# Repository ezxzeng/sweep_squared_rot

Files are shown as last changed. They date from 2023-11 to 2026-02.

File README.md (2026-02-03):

# Sweep Squared
## An autogenerated split 36 key keyboard
example zmk config at https://github.com/ezxzeng/sweepsq-zmk

## Disclaimer

Please do not rely on the autogenerated files and double check them manually
before sending them off to a PCB fab. The author and other random strangers on the internet have been able to produce
working keyboard prototypes from this repo; this does not mean that everything will work every time.

The author(s) waive(s) responsibility for any damage or regulatory violations caused by using this software (see
license). Please consult your local regulations around radio frequencies and what's allowed for DIY projects in your
country.

left | right | outline
-|-|-
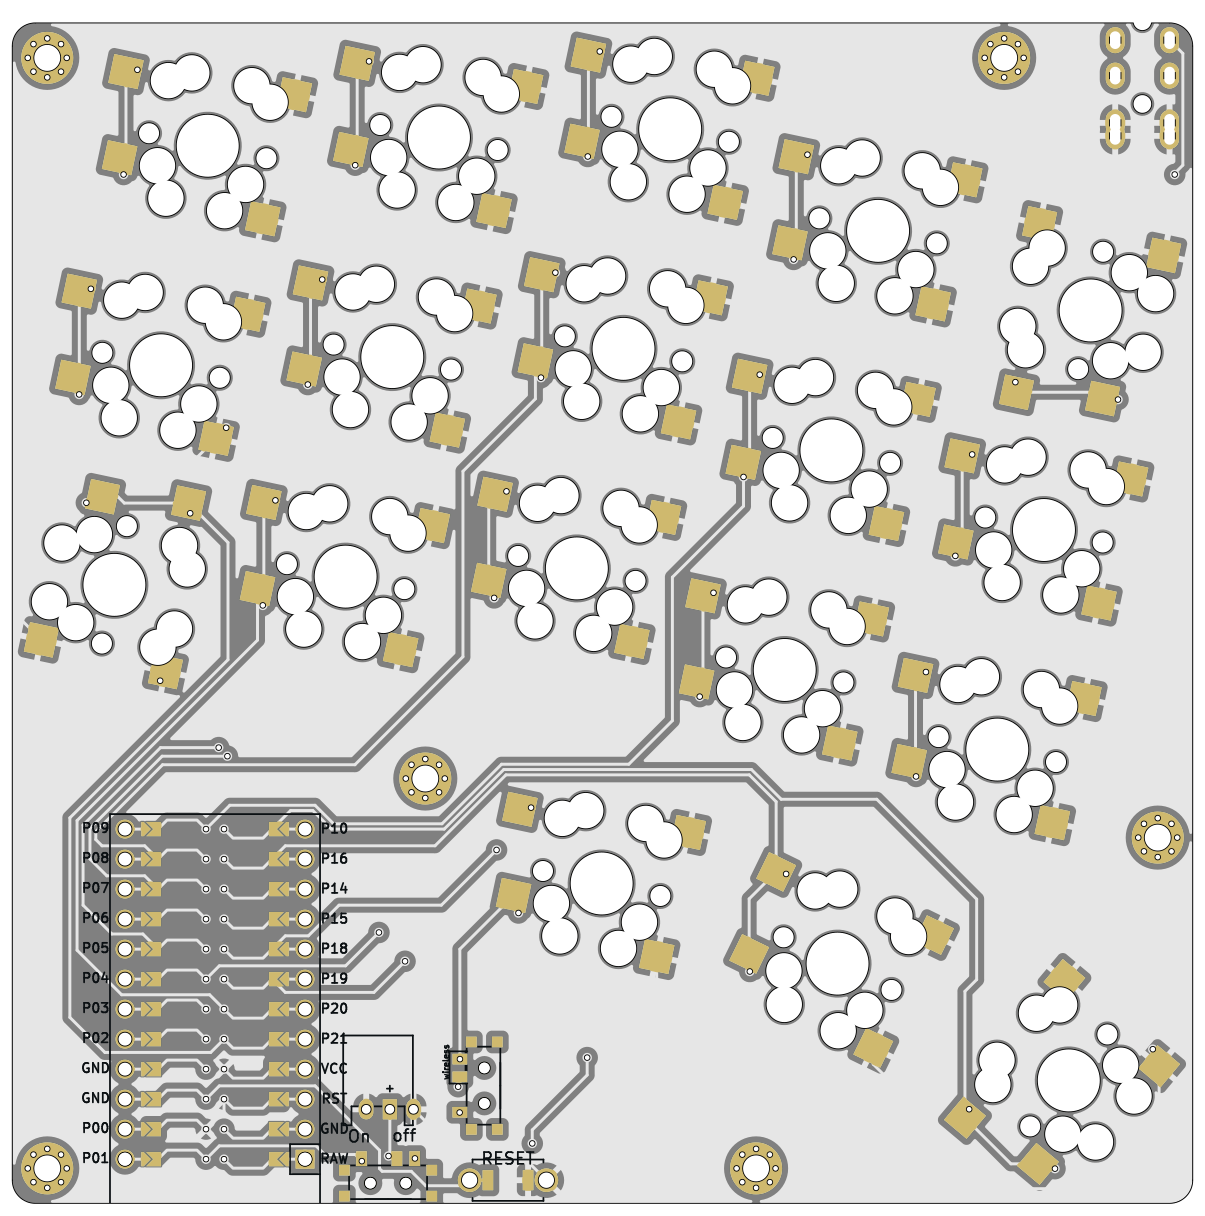
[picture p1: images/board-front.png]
left
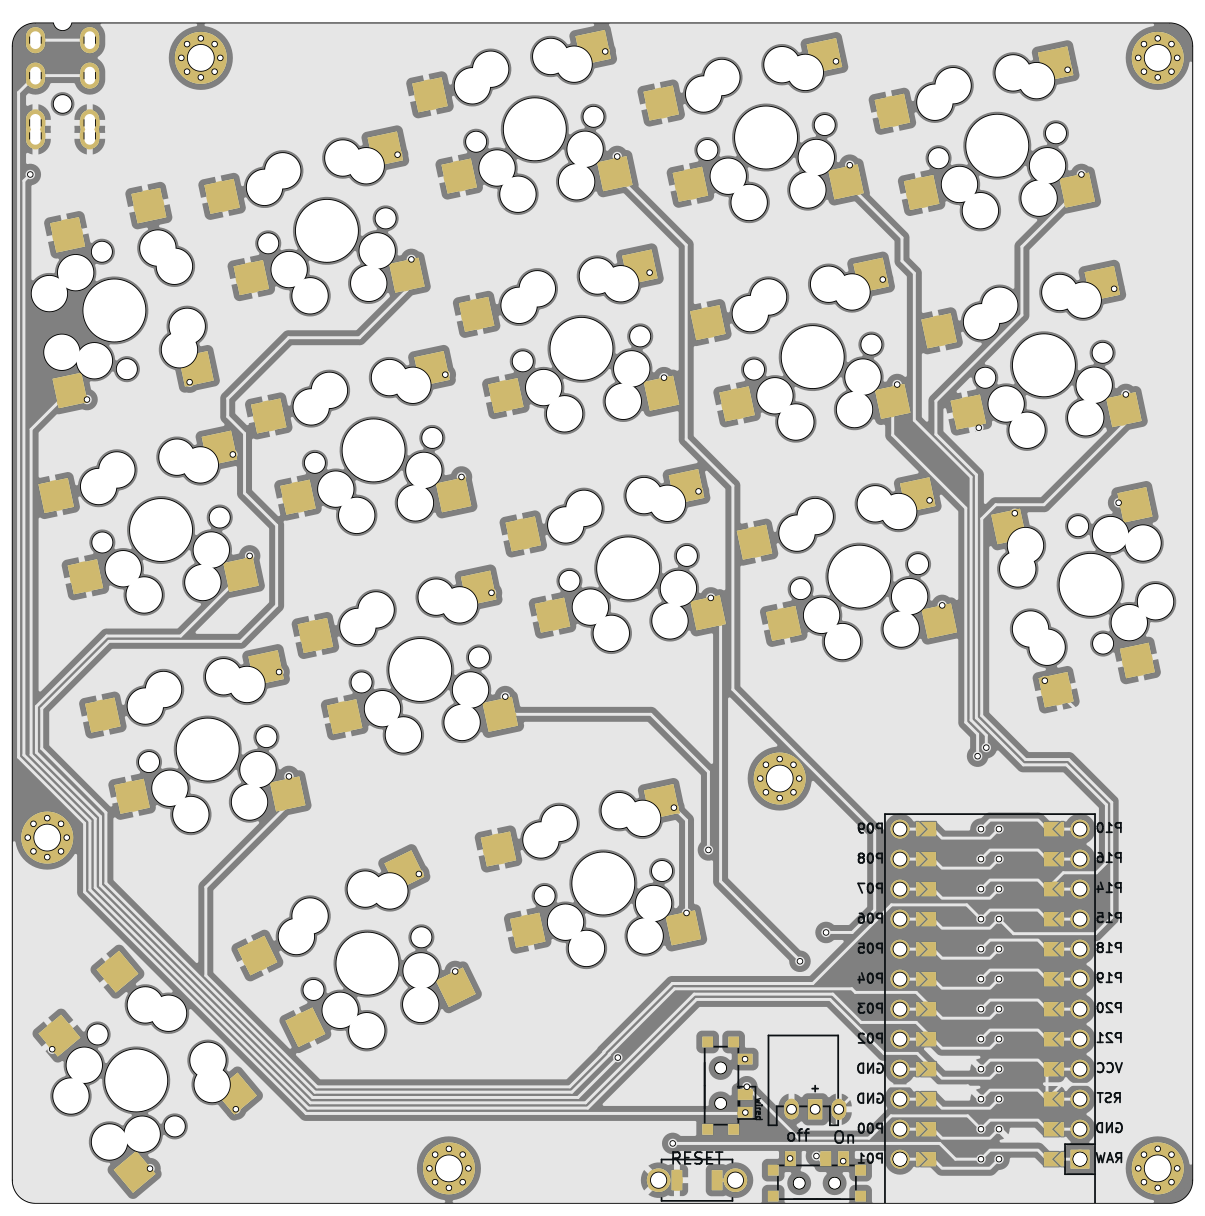
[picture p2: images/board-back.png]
right
 |  | outline

A 5x3 split keyboard with 3 thumb keys. 

## Inspiration

- [bgkeeb](https://github.com/sadekbaroudi/bgkeeb)
	- keyboard pcbs under 100mm x 100mm are cheap
- [cheapis](https://github.com/dotleon/cheapis)
	- sweeps can be rotated for more room and length between the thumb cluster and rest of the keys and still fit within 100mm x 100mm
- [samoklava](https://github.com/soundmonster/samoklava) and [ergogen](https://ergogen.cache.works/) to get keyboard layouts programatically
- [sweep](https://github.com/davidphilipbarr/Sweep) and [swweeep](https://github.com/sadekbaroudi/sweep36) for form factor and diode-less design
- [Lily58](https://github.com/kata0510/Lily58/tree/master)
	- key sockets can be hot swappable, reversible, and compatible with both mx and low profile switches
- [totem](https://github.com/GEIGEIGEIST/totem)
	- sandwich case looks really slick and clean, and can also hide the controller parts that will be located under the palm

## Features

- 100mm x 100mm pcb for really cheap fabrication
- reversible footprint
- programatically generated with [ergogen](https://ergogen.cache.works/) (mostly)
- `footprints/key_switches.js` enables deciding between combinations of MX, Choc, or gateron low profile sockets
- jst battery connector and 7-pin slider switch for battery management
- Same key routing as the [swweeep](https://github.com/sadekbaroudi/sweep36)
- Can be both wired and wireless while maintaining a diodless design
  - Features a toggle button to change whether p0 directs to TRRS or the inner thumb key
  - This does mean that the wired version would only support two thumb keys

## Other considerations
- this design does not support LEDs or displays
- [samoklava's](https://github.com/soundmonster/samoklava) auto routing does not really work here

## Rendering and generation

### Generate config:
```bash
python generate_config.py
```
Alternatively, edit the units of base_units.yaml with files from the `unit_diffs` folder.

For example, to generate a case compatible with gateron low profile keyboards and a 1u thumb key instead of 1.5u:
```bash
python generate_config.py unit_diffs/1u_thumb.yaml unit_diffs/gateron_lp_case.yaml 
```

### Ergogen:
```bash
ergogen .
```

### Case:
```bash
for i in output/cases/*.jscad; do npx @jscad/cli@1 "$i" -of stla; done
```

Alternatively, checkout the [onshape file](https://cad.onshape.com/documents/20657883be99e0a9d477d709/w/83f1c619a76dd7448d8e6516/e/9a5a09390163f484d61154c1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) for nicer cases

### Get board image renderings:
```bash
docker run -v $(pwd):/kikit --entrypoint pcbdraw yaqwsx/kikit:v1.3.0-v7  plot --style style.json routed_pcb/board.kicad_pcb images/board-front.png

docker run -v $(pwd):/kikit --entrypoint pcbdraw yaqwsx/kikit:v1.3.0-v7  plot --style style.json --side back routed_pcb/board.kicad_pcb images/board-back.png
```

## Showcase

combined
tented_mx
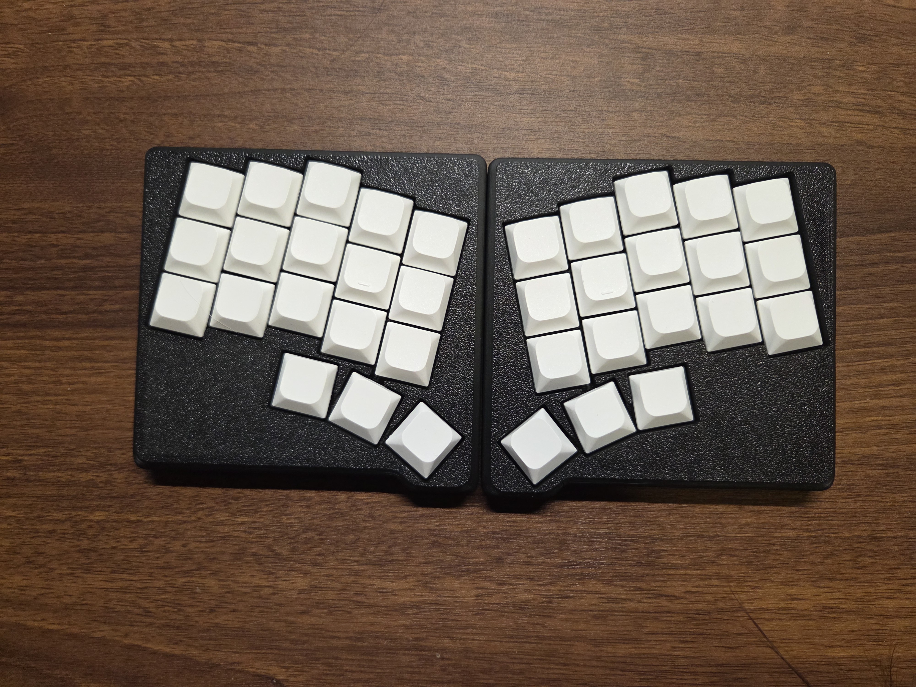
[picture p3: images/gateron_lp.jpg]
gateron_lp


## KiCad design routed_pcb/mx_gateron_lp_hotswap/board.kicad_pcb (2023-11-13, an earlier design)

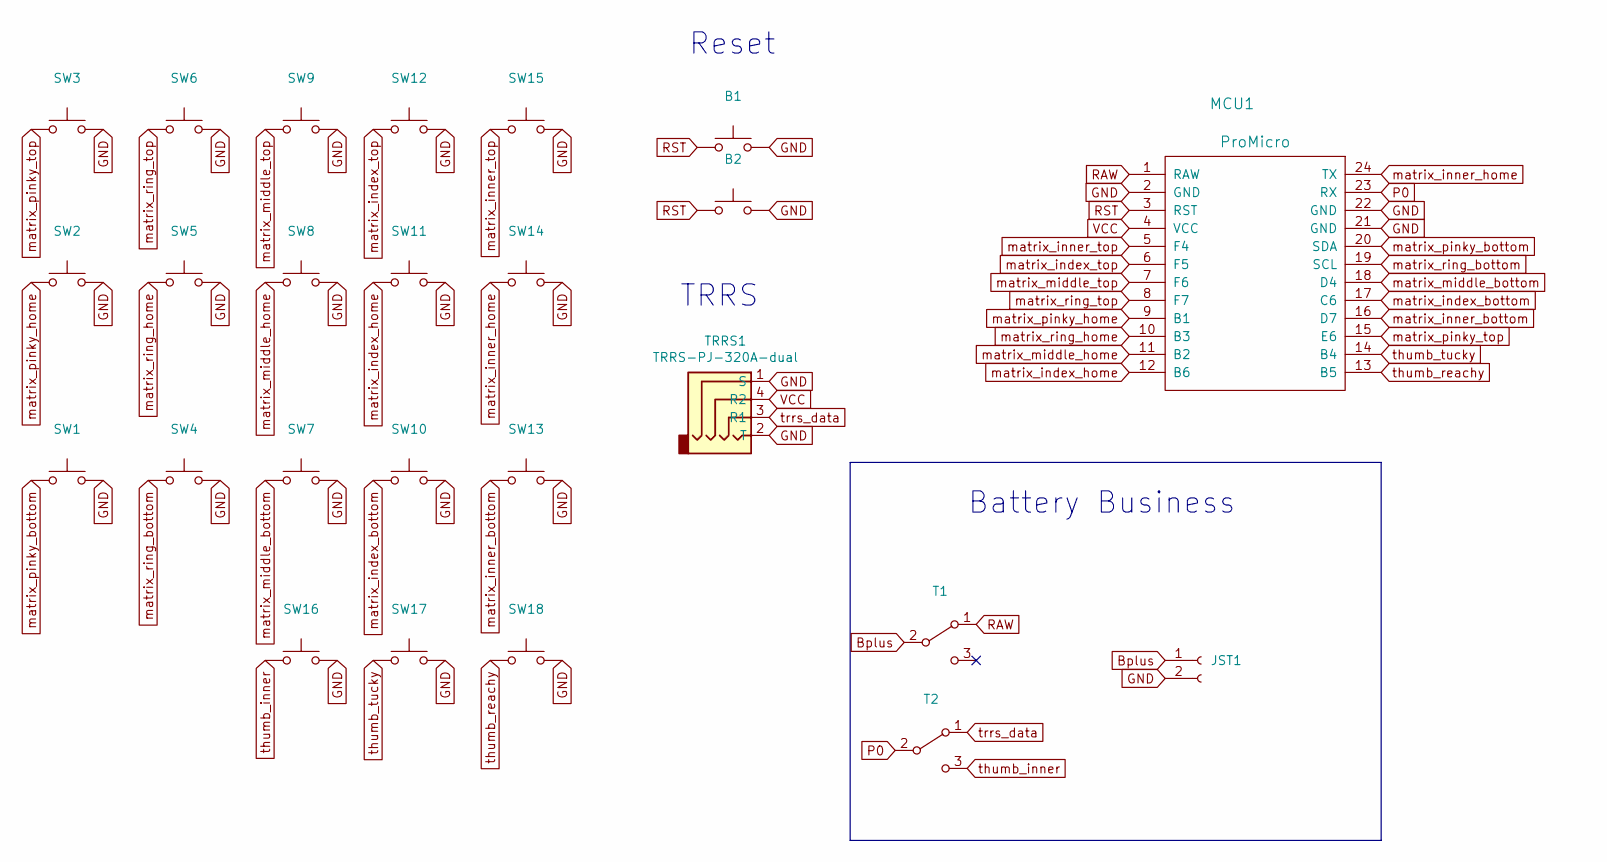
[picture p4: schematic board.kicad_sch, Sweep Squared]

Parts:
B1: ResetSW
B2: SW_SPST_B3U-1000P
JST1: JST_PH_S2B-PH-K_02x2.00mm_Angled
MCU1: ProMicro
SW1, SW2, SW3, SW4, SW5, SW6, SW7, SW8, SW9, SW10, SW11, SW12, SW13, SW14, SW15, SW16, SW17, SW18: key-switches
T1, T2: SPDT_C128955
TRRS1: TRRS-PJ-320A-dual

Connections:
/Bplus: JST1.1, T1.2 (B)
/GND: B1.2, B2.2 (1), JST1.2, MCU1.2 (GND), MCU1.21 (GND), MCU1.22 (GND), SW1.2, SW2.2, SW3.2, SW4.2, SW5.2, SW6.2, SW7.2, SW8.2, SW9.2, SW10.2, SW11.2, SW12.2, SW13.2, SW14.2, SW15.2, SW16.2, SW17.2, SW18.2, TRRS1.1 (S), TRRS1.2 (T)
/P0: MCU1.23 (RX), T2.2 (B)
/RAW: MCU1.1 (RAW), T1.1 (A)
/RST: B1.1, B2.1 (2), MCU1.3 (RST)
/VCC: MCU1.4 (VCC), TRRS1.4 (R2)
/matrix_index_bottom: MCU1.17 (C6), SW10.1
/matrix_index_home: MCU1.12 (B6), SW11.1
/matrix_index_top: MCU1.6 (F5), SW12.1
/matrix_inner_bottom: MCU1.16 (D7), SW13.1
/matrix_inner_home: MCU1.24 (TX), SW14.1
/matrix_inner_top: MCU1.5 (F4), SW15.1
/matrix_middle_bottom: MCU1.18 (D4), SW7.1
/matrix_middle_home: MCU1.11 (B2), SW8.1
/matrix_middle_top: MCU1.7 (F6), SW9.1
/matrix_pinky_bottom: MCU1.20 (SDA), SW1.1
/matrix_pinky_home: MCU1.9 (B1), SW2.1
/matrix_pinky_top: MCU1.15 (E6), SW3.1
/matrix_ring_bottom: MCU1.19 (SCL), SW4.1
/matrix_ring_home: MCU1.10 (B3), SW5.1
/matrix_ring_top: MCU1.8 (F7), SW6.1
/thumb_inner: SW16.1, T2.3 (C)
/thumb_reachy: MCU1.13 (B5), SW18.1
/thumb_tucky: MCU1.14 (B4), SW17.1
/trrs_data: T2.1 (A), TRRS1.3 (R1)

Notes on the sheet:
TRRS
Battery Business
Reset

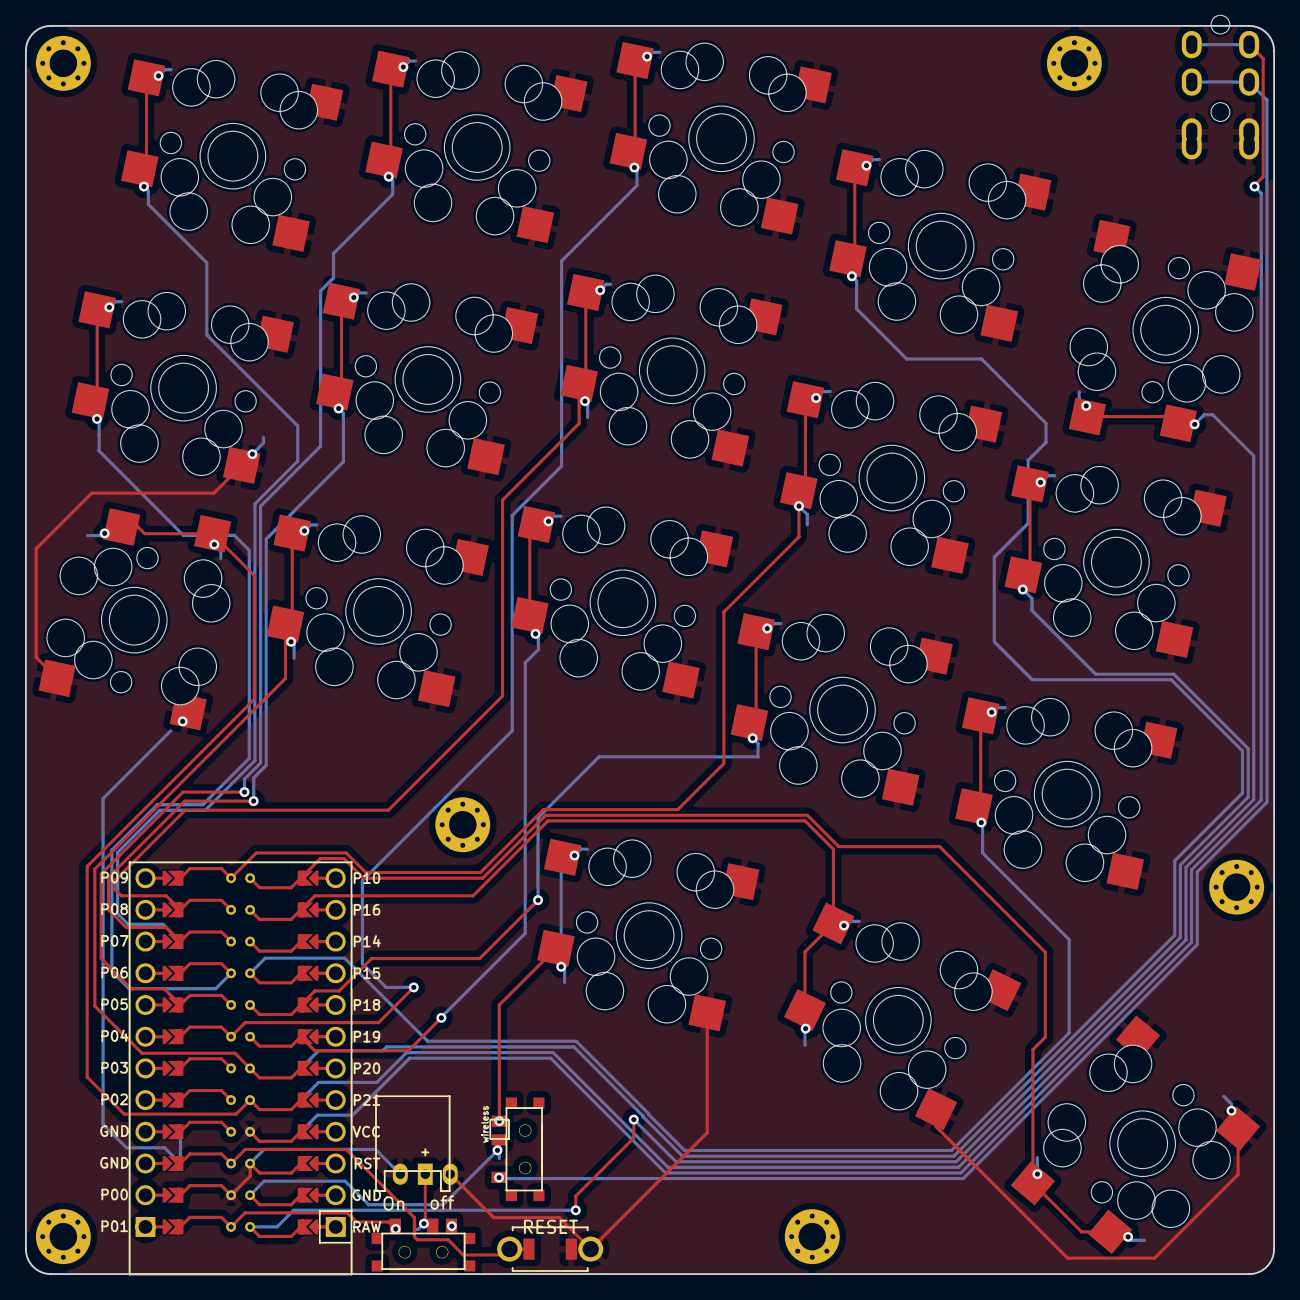
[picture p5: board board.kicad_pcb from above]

Board: 2 copper layers, 100.0 x 100.0 mm, 31 parts (0 on the bottom side), 25 nets.

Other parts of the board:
HOLE1, HOLE2, HOLE3, HOLE4, HOLE5, HOLE6: MountingHole_2.2mm_M2_Pad_Via

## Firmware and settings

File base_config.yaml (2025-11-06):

points:
  zones:
    matrix:
      # Fix placement on KiCAD sheet.
      anchor.shift: [100, -100]
      key:
        padding: 1ky
        spread: 1kx
      rotate: -12
      columns:
        pinky:
          rows.bottom:
            rotate: -90
          rows.home:
            rotate: 90
            shift: [-1kx, -1kx]
        ring.key:
          stagger: 0.25kx
        middle.key.stagger: 0.25kx
        index.key.stagger: -0.25kx
        inner:
          key.stagger: -0.15kx
          rows.top.rotate: 90
      rows:
        bottom.padding: kx
        home.padding: kx
        top.padding: kx
    thumb:
      anchor:
        ref: matrix_middle_bottom
        shift: [0.4kx, -1.35kx]
      columns:
        inner:
          key.name: thumb_inner
        tucky:
          key:
            name: thumb_tucky
            stagger: -2
            splay: -14
            shift: [2, 0]
        reachy:
          key.spread: kx
          key.splay: -14
          key.stagger: 3
          key.origin: [-0.5kx, -0.5kx]
          key.shift: [3, 0]
          key.rotate: 90
          key.width: thumb_size * kx
          key.name: thumb_reachy
outlines:
  # ==================== keys ====================
  _thumb:
    - what: rectangle
      where: thumb_reachy
      bound: true
      size: [thumb_size * kx, ky]
  _padded_thumb:
    - what: rectangle
      where: thumb_reachy
      bound: true
      size: [thumb_size * px, py]
  _keys:
    - what: rectangle
      where: true
      size: [kx, ky]
  _padded_keys:
    - what: rectangle
      where: true
      size: [px, py]
  key_outline:
    - name: _keys
    - +_thumb
  _expanded_key_outline:
    - name: _padded_keys
    - +_padded_thumb
  _limits:
    - what: rectangle
      size: [100, 100]
      adjust.shift: [center_x, center_y]
  combo:
    - name: _limits
    - operation: stack
      name: _keys
    - operation: stack
      name: _thumb
  pcb_outline:
    - what: polygon
      points:
        - shift: [center_x-50, center_y+50]
        - shift: [100, 0]
        - shift: [0, -100]
        # - shift: [-40, 0]
        # - shift: [-15, 15]
        # - shift: [-45, 0]
        - shift: [-100, 0]
      fillet: 2
  pcb_outline_combo:
    - name: pcb_outline
    - operation: stack
      name: _keys
    - operation: stack
      name: _limits
  # ==================== case ====================
  _case_outline:
    - what: polygon
      points:
        - shift: [center_x-50-case_left_padding, center_y+50+case_top_padding] # top left of case
        - shift: [100+case_left_padding+case_right_padding, 0] # top right of case
        - shift: [0, -100-case_top_padding-case_bottom_padding-case_to_pcb] # bottom right of case
        - shift: [-1*case_thumb_traverse, 0] # bottom left of thumb
        - shift: [-1*case_bottom_padding, case_bottom_padding] # angled up following thumb
        - shift: [case_thumb_traverse+case_bottom_padding-case_left_padding-case_right_padding-100, 0] # bottom left of case
      fillet: 2
  _case_outline_xl:
    - what: polygon
      points:
        - shift: [center_x-50-case_left_padding-wall_thickness, center_y+50+case_top_padding+wall_thickness]
        - shift: [100+case_left_padding+case_right_padding+(wall_thickness*2), 0]
        - shift: [0, -100-case_top_padding-case_bottom_padding-case_to_pcb-(wall_thickness*2)]
        - shift: [-1*case_thumb_traverse-(wall_thickness*1.5), 0]
        - shift: [-1*case_bottom_padding, case_bottom_padding]
        - shift: [case_thumb_traverse+case_bottom_padding-case_left_padding-case_right_padding-100-(wall_thickness*0.5), 0]
      fillet: 2
  # ==================== mounting ====================
  _mounting:
    - what: circle
      where.shift: [mounting_1_x, mounting_1_y]
      radius: screwSize
    - what: circle
      where.shift: [mounting_2_x, mounting_2_y]
      radius: screwSize
    - what: circle
      where.shift: [mounting_3_x, mounting_3_y]
      radius: screwSize
    - what: circle
      where.shift: [mounting_4_x, mounting_4_y]
      radius: screwSize
    - what: circle
      where.shift: [mounting_5_x, mounting_5_y]
      radius: screwSize
    - what: circle
      where.shift: [mounting_6_x, mounting_6_y]
      radius: screwSize
  _mounting_case_only:
    - what: circle
      where.shift: [mounting_7_x, mounting_7_y]
      radius: screwSize
    - what: circle
      where.shift: [mounting_8_x, mounting_8_y]
      radius: screwSize
  _mounting_tight:
    - what: circle
      where.shift: [mounting_1_x, mounting_1_y]
      radius: screwSize_tight
    - what: circle
      where.shift: [mounting_2_x, mounting_2_y]
      radius: screwSize_tight
    - what: circle
      where.shift: [mounting_3_x, mounting_3_y]
      radius: screwSize_tight
    - what: circle
      where.shift: [mounting_4_x, mounting_4_y]
      radius: screwSize_tight
    - what: circle
      where.shift: [mounting_5_x, mounting_5_y]
      radius: screwSize_tight
    - what: circle
      where.shift: [mounting_6_x, mounting_6_y]
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

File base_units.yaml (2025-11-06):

# `U` is a predefined unit of measure that means 19.05mm, which is MX spacing
units:
  # Proxy Spacing Variables for easy changing to choc/mx
  kx: 19
  ky: 19
  # Padding Variables
  px: kx + 1.2
  py: ky + 1.2
  center_x: 118.34
  center_y: -121
  
  thumb_size: 1.5 # U
  top_case_height: 9
  
  # ==================== case outline ====================
  # assume 100x100 pcb
  case_left_padding: 5
  case_top_padding: 4
  case_right_padding: 8
  case_bottom_padding: 9
  case_thumb_traverse: 40 # amount of x mm before 45 degree angle up to meet the pcb
  case_to_pcb: 0.3 # tolorance from bottom to switch
  wall_thickness: 2
  # ==================== mounting ====================
  # Defaults to M2 Screws
  screwSize: 2
  screwSize_tight: 1.2
  standoffSize: 2.5
  bottom_screwhole_wall: 3.5
  # 65.9, 81
  mounting_1_x: center_x-47
  mounting_1_y: center_y+47 
  # 146.65, 81
  mounting_2_x: center_x+34 
  mounting_2_y: center_y+47 
  # 158.5, 146 mm
  mounting_3_x: center_x+47
  mounting_3_y: center_y-19
  # 125.65, 172
  mounting_4_x: center_x+13
  mounting_4_y: center_y-47 
  # 102.65, 142
  mounting_5_x: center_x-15
  mounting_5_y: center_y-14
  # 65.9, 138
  mounting_6_x: center_x-47
  mounting_6_y: center_y-47

  mounting_7_x: center_x+55
  mounting_7_y: center_y+47  
  mounting_8_x: center_x+55.2
  mounting_8_y: center_y-56.2
  
  # ==================== object locations ====================
  mcu_x: -32.8
  mcu_y: -32.25
  
  trrs_x: 48
  trrs_y: 51.7
  
  reset_x: -8
  reset_y: -48
  
  power_x: -18.15
  power_y: -48.25
  
  wireless_x: -10
  wireless_y: -40
  
  jst_x: -18
  jst_y: -42
  
  # ==================== power switch extension ====================
  ps_ext_supp_x: 4.9 # x length of switch extension supports on each side
  ps_ext_supp_x_padding: 2.5 # x length to subtract from the wall on each side to allow the switch to move
  ps_ext_supp_thickness: 0.8 # thickness of switch extension supports on each side
  ps_ext_supp_to_wall: 0.2
  ps_hole_x: 6.5 # length of hole to leave in case wall
  ps_ext_cuttout_x: 1.6
  ps_ext_cuttout_y: 1.4
  ps_outer_x: 3.2
  ps_outer_y_from_wall: 0.5 # distance from switch support to inner wall
  ps_backsupp_thickness: 0.8
  ps_backsupp_low_x: 8 # length of shorter back support, centered on switch
  ps_backsupp_low_z_subtract: 2.55
  ps_backsupp_tall_x: 18 # length of tall back support, right of lower
  ps_hole_z: 2.75
  ps_cuttout_z: 2.2 # measured from bottom of pcb
  
  # ==================== case ====================
  mounting_top_extrude: 5
  
  pcb_thickness: 1.6
  bottom_case_height: 3.5 # height to touching pcb, not counting outer wall
  bottom_standoff_thickness: 1.5
  bottom_thickness: 1.5
  
  # control area
  control_area_ceil_thickness: 1
  
  # plate variables
  plate_switch_hole_x: 14.5
  plate_switch_hole_y: 14.5
  plate_support_x: 8.2
  plate_support_y: 16.2
  plate_z: 4.5 # from pcb to top of plate
  plate_thickness: 0.6 # from plate to plate support
  
  # openings
  usbc_x: 10
  usbc_z: 3.75
  reset_hole_x: 8.5
  reset_hole_y: 2.7
  reset_hole_fillet: 1.349
  
  # ==================== switches ====================
  mx_spacing: 1
  millmax_diameter: 1.6
  mx: 1
  mx_hotswap: 1
  mx_reverse: 1
  mx_pth: 0
  mx_rev_pad: 1
  gateron_lp: 1
  gateron_lp_hotswap: 1
  gateron_lp_reverse: 1
  gateron_lp_pth: 0
  gateron_lp_rev_pad: 1
  gateron_lp_neg_y: 1
  choc: 0
  choc_hotswap: 0
  choc_millmax: 0
  choc_reverse: 0
  choc_pth: 0
  choc_neg_y: 1
  keycaps: 1
  
  # ==================== 3d printing ====================
  layer_height_3dp: 0.2
  

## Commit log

2023-11-12 export gerbers from routed_pcb
2023-11-12 pcb rendered with pcbdraw
2023-11-12 reset gerber action to original
2023-11-12 updated pcb images
2023-11-12 custom pcb style
2023-11-12 moved text on pro micro
    [board.kicad_pcb]
2023-11-13 mirror texts on back side
    [board.kicad_pcb]
2023-11-13 switched pad ordering of nonhotswap choc
2023-11-13 added variable millmax diameter support
2023-11-20 added 2 new mounting holes for the case
2023-11-24 added case configs
2024-01-06 fixed case
2024-02-05 moved routed pcb to subfolder
    [board.kicad_pcb, board.kicad_sch]
2024-02-05 bottom standoff bug
2024-02-05 fixed changing key_switches using unit variables
    [base_config.yaml, base_units.yaml]
2024-08-04 case config fixes, mx_choc_pcb
    [board.kicad_pcb]
2025-03-17 changed case to make it more lenient to print errors
    [base_config.yaml, base_units.yaml]
2025-11-06 finished case, readme edit
2026-02-09 mounting hole has size as parameter
2026-03-14 removed footprints folder in prep of making it a submodule
2026-03-14 added footprints as submodules
